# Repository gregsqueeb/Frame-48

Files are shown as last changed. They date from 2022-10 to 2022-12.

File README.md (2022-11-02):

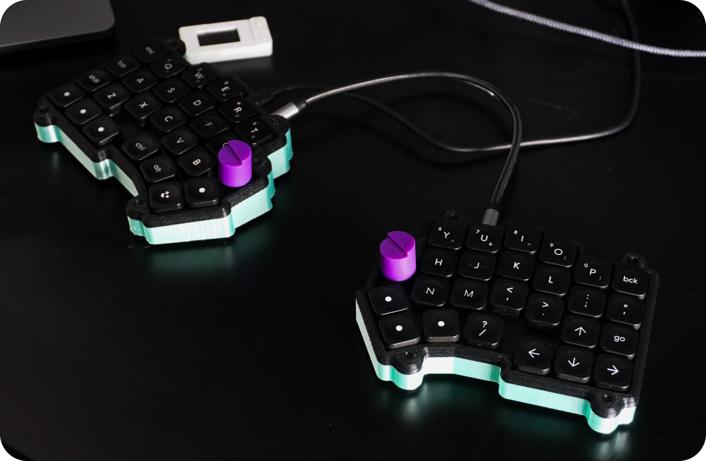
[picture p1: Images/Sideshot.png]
Side Shot

# Frame 48
 A handwired keyboard build created to use the [WorkLouder](https://worklouder.cc/) keycaps and inspired by the Void Ergo S! Runs QMK firmware and fully customizable with VIA configurator.

The Frame 48 is a 3d printed, handwired, split keyboard that was inspired by the [VOID ergo S](https://github.com/victorlucachi/void_ergo), running QMK Firmware on [Adafruit KB2040](https://www.adafruit.com/product/5302) controllers. Connection between the two halves of the keyboard is made with an aux cable via serial.

I suggest printing the case using a 0.4 mm nozzle, supports are not needed.

The brass inserts can be fixed in the bottom case by heating them and applying pressure with a soldering iron set to about 200-220C.

I created this iteration of the VOID Ergo S because I wanted my keyboard to have arrow keys as I use them a lot in my work as a product designer. I also wanted to build a keyboard that utilized [WorkLouder](https://worklouder.cc/) keycaps because I am a huge fan of their design and product. To be able to use their keycaps I needed to use choc style low profile switches which I couldn't get to work with the original Void Ergo S.

[Build Guide](/STL%20Files/Readme.md)

# Bill of Materials

* 52 diodes (tme.eu [link](https://www.tme.eu/ro/en/details/1n4148-dio/tht-universal-diodes/diotec-semiconductor/1n4148/)/aliexpress [link](https://www.aliexpress.com/item/32729204179.html))
* [Work Louder Keycaps](https://worklouder.cc/shop/wrk-legend/). This build was designed with these keycaps in mind.
* 52/54 choc switches [link](https://mechanicalkeyboards.com/shop/index.php?l=product_detail&p=6337)
* 24 AWG (0.2 mm2) wire
* 2 × [Adafruit KB2040](https://www.adafruit.com/product/5302)
* 1 × [Copper Wire](https://www.amazon.com/dp/B00XHD03EA) for switch connections
* 2 × EC11 Rotary Encoder (optional/aliexpress [link](https://www.aliexpress.com/item/32872039030.html) mounted to the plate using [this adapter](https://www.thingiverse.com/thing:3770166))
* 10 × M2×12 allen head screws (aliexpress [link](https://www.aliexpress.com/item/32966941844.html), 14mm overall length, 4mm diameter head)
* 10 × M2 brass inserts (aliexpress [link](https://www.aliexpress.com/item/4000585933306.html), 3.5mm outer diameter)
* 2 × PJ320A 3.5mm female audio connectors (aliexpress [link](https://www.aliexpress.com/item/32368285821.html))
* hot glue for securing the KB2040 to the bottom case (optional, but recommended), the audio connectors, and the switches.

# Pin assignment

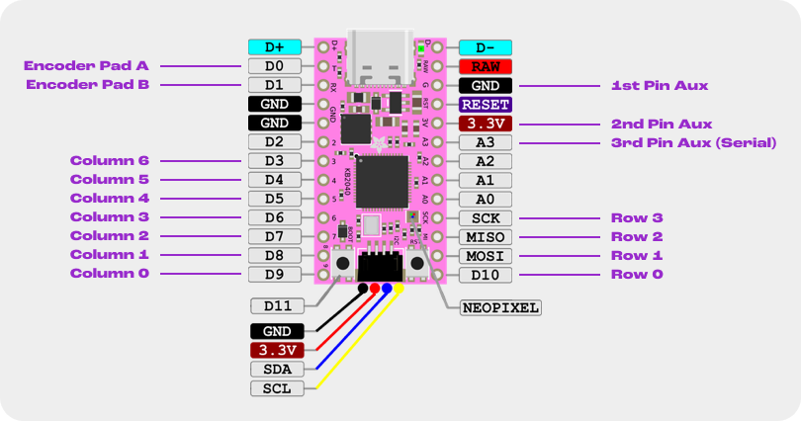
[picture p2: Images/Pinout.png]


    ROW0    ROW1    ROW2    ROW3
    D10     MOSI    MISO    SCK

    COL0    COL1    COL2    COL3    COL4    COL5    COL6
    D9      D8      D7      D6      D5      D4      D3

    Encoder Pad A           Encoder Pad B
    DO                      D1

    Serial Pin
    A3

*Matrix layout*
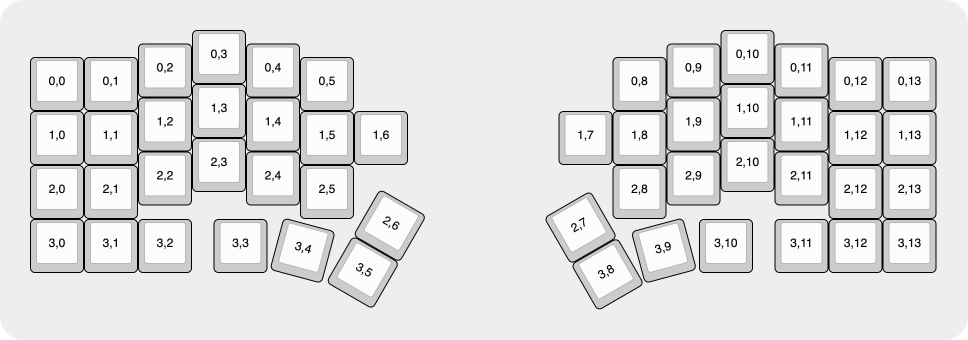
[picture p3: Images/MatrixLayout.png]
Matrix Layout

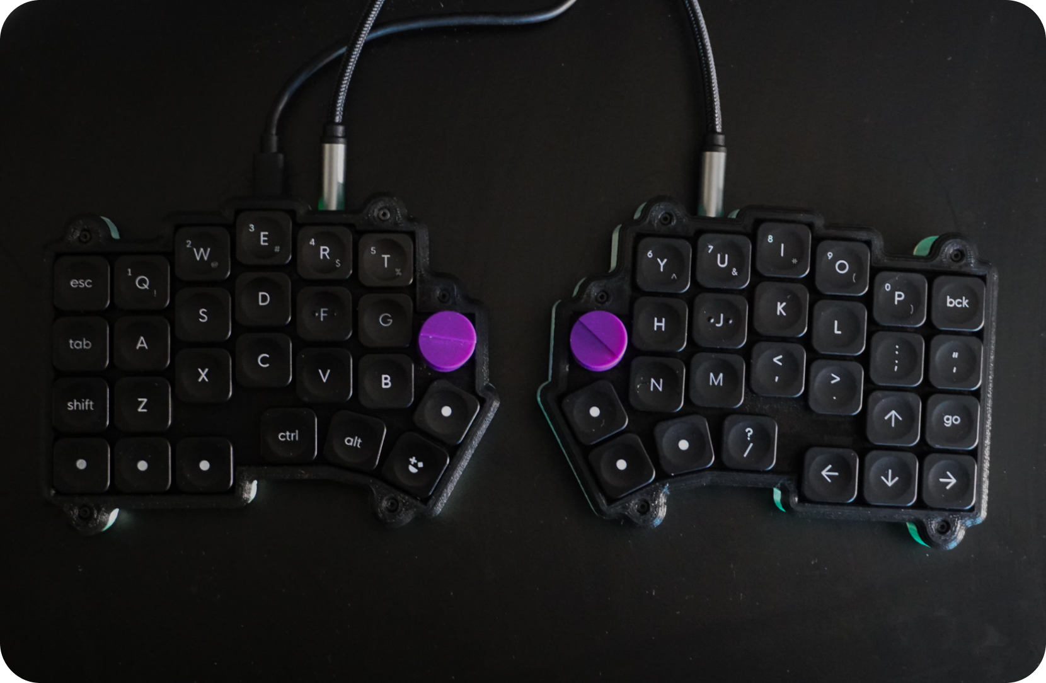
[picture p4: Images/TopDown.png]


# QMK Files
I have included the raw [QMK files](</QMK Files>) to compile the firmware in addition to the [copiled firmware](</Compiled Firmware>) for the keyboard to make it easier for people who don't want to compile their own firmware.

# [VIA Configurator Layout](https://usevia.app/)
I have created a VIA Configurator design for the board as well so it is easier to see what you are editing. You can upload the JSON file in [this folder](</VIA Files>) to the [Design tab](https://usevia.app/#/design) of VIA Configurator

# 💖 Inspiration and Thanks 💖
Huge shout out to [Victor Luchachi](https://victorlucachi.ro/) who makes absolutely beautiful products and renders. The design language of this build is based off of his Void Ergo S keyboard and his VOID 16 build was my very first keyboard build.

Thank you so much to [Joe Scotto](https://www.youtube.com/joescotto) for his awesome videos on handwiring keyboards. His pictures on reddit inspired me to use copper wiring on my build which ended up making the wiring process much easier and looks much much cleaner.

A massive fanboy shoutout to [WorkLouder](https://worklouder.cc/) for creating an absolutely beautiful and high quality product. The design of your keyboards and keycaps are amazing!

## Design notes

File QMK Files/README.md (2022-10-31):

1. Drag frame_48 in the qmk_firmware/keyboards/handwired/ folder

2. From the qmk_firmware folder run `make handwired/frame_48:via`

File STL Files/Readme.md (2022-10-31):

# Build Guide

1. Print all files :) 
    For the keyplates print them face down. You won't have to use supports for any of the prints.

2. Pop those switches in the key plate from the top.
switches

3. Bend all the diodes. I twist a little loop on the side that doesn't have a black line, and then perpendicular to the loop I bend the other half up.
diodes

4. Put the loop on the switch and solder them to the key
diode on key

5. Bend your wire for the rows, then bend the half of the diode that is facing straight up around the wire and solder it to the wire.
row soldered

6. Solder the columns all together. Use heat shrink tubing where the columns go over the rows.
row soldered

7. You will wire in the rotary encoder to the matrix. On the side with just two pins coming off the encoder, put a diode on one side and connect it to the rows, on the other pin connect that to the column. This will make the "push" work as a key. To wire the twist you will wire up the side with 3 pins. The outside pins connect to the microcontroller and the inside pin connects to ground on the microcontroller.

8. Wire columns and rows to the micro-controler. Use the pin diagram to make sure you are wiring the correct row/column to the correct pin.
Pinout

9. Solder wires to the TRRS port and wire that up to the micro controller. Make sure you are consistent with the wiring on both halfs.

10. Put everything in the case, use hot glue to secure the microcontroller and the TRRS connector.

11. Use your soldering iron ar ~200-220c and melt the M2 brass inserts into the bottom case.

12. Screw everything together!
Final

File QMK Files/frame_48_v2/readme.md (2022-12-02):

# Frame 48

frame

*A handwired keyboard build created to use the [WorkLouder](https://worklouder.cc/) keycaps and inspired by the Void Ergo S! Runs QMK firmware and fully customizable with VIA configurator.*

*The Frame 48 is a 3d printed, handwired, split keyboard that was inspired by the [VOID ergo S](https://github.com/victorlucachi/void_ergo), running QMK Firmware on [Adafruit KB2040](https://www.adafruit.com/product/5302) controllers. Connection between the two halves of the keyboard is made with an aux cable via serial.*

* Keyboard Maintainer: [Greg Mathews](https://github.com/gregsqueeb)
* Hardware Supported: Adafruit KB2040
* Hardware Availability:
  * 56 diodes (tme.eu [link](https://www.tme.eu/ro/en/details/1n4148-dio/tht-universal-diodes/diotec-semiconductor/1n4148/)/aliexpress [link](https://www.aliexpress.com/item/32729204179.html))
  * [Work Louder Keycaps](https://worklouder.cc/shop/wrk-legend/). This build was designed with these keycaps in mind.
  * 54/56 choc switches [link](https://mechanicalkeyboards.com/shop/index.php?l=product_detail&p=6337)
  * 24 AWG (0.2 mm2) wire
  * 2 × [Adafruit KB2040](https://www.adafruit.com/product/5302)
  * 1 × [Copper Wire](https://www.amazon.com/dp/B00XHD03EA) for switch connections
  * 2 × EC11 Rotary Encoder (optional/aliexpress [link](https://www.aliexpress.com/item/32872039030.html) mounted to the plate using [this adapter](https://www.thingiverse.com/thing:3770166))
  * 10 × M2×12 allen head screws (aliexpress [link](https://www.aliexpress.com/item/32966941844.html), 14mm overall length, 4mm diameter head)
  * 10 × M2 brass inserts (aliexpress [link](https://www.aliexpress.com/item/4000585933306.html), 3.5mm outer diameter)
  * 2 × PJ320A 3.5mm female audio connectors (aliexpress [link](https://www.aliexpress.com/item/32368285821.html))
  * hot glue for securing the KB2040 to the bottom case (optional, but recommended), the audio connectors, and the switches.

Make example for this keyboard (after setting up your build environment):

    make handwired/frame_48:default

Flashing example for this keyboard:

    make handwired/frame_48:default:flash

## Bootloader

Enter the bootloader:
    Press and hold the BOOT button down.
    Press and release the Reset button.
    Continue holding the BOOT button until you see the RPI-RP2 drive appear.
    You can now release but BOOT button.

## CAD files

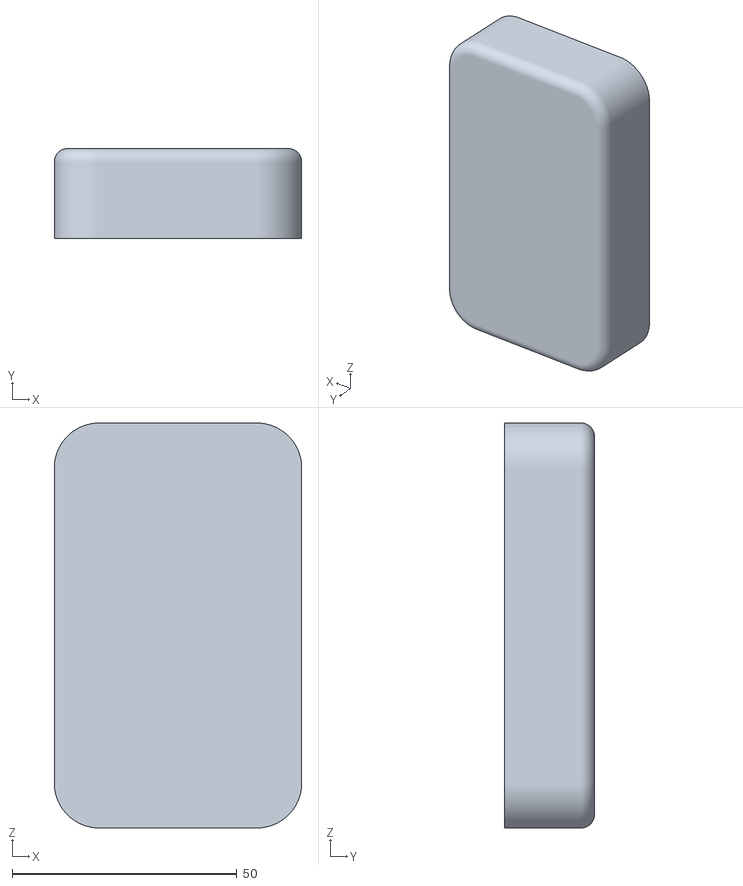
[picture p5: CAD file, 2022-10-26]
STL Files/Wrist Pad.stl
55.0 x 20.0 x 90.0

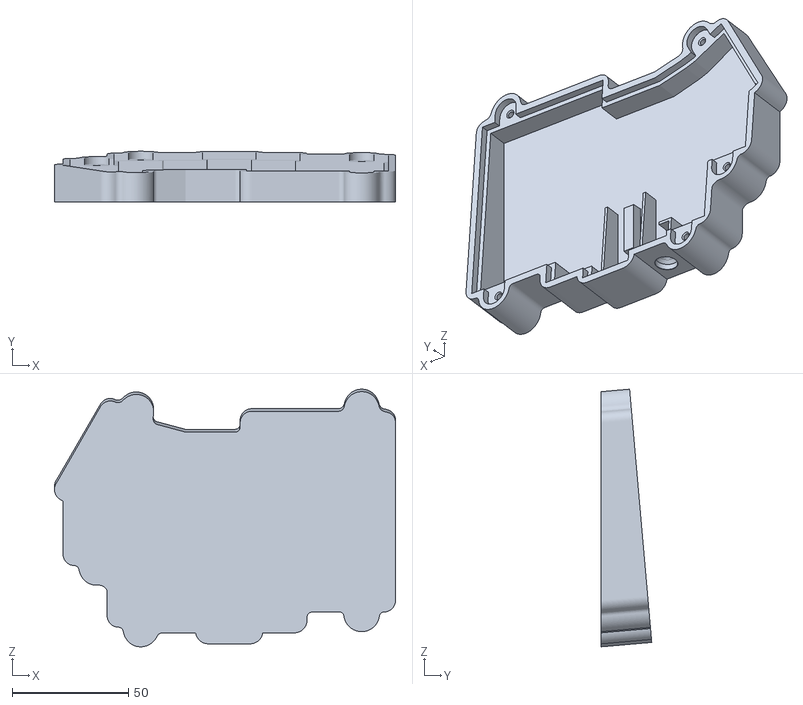
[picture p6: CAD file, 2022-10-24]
STL Files/Base-Right.stl
146.6 x 21.7 x 110.8

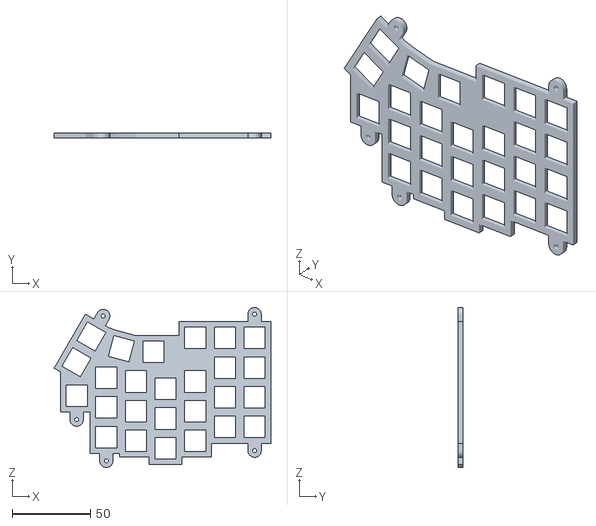
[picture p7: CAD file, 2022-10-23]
STL Files/KeyPlate-Left.stl
139.0 x 3.00 x 102.5

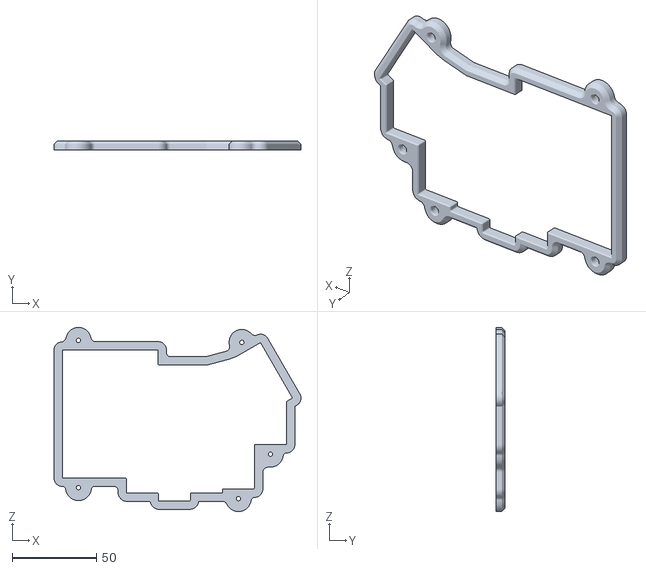
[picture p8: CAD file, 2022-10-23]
STL Files/TopPlate-Left.stl
146.6 x 5.50 x 109.3

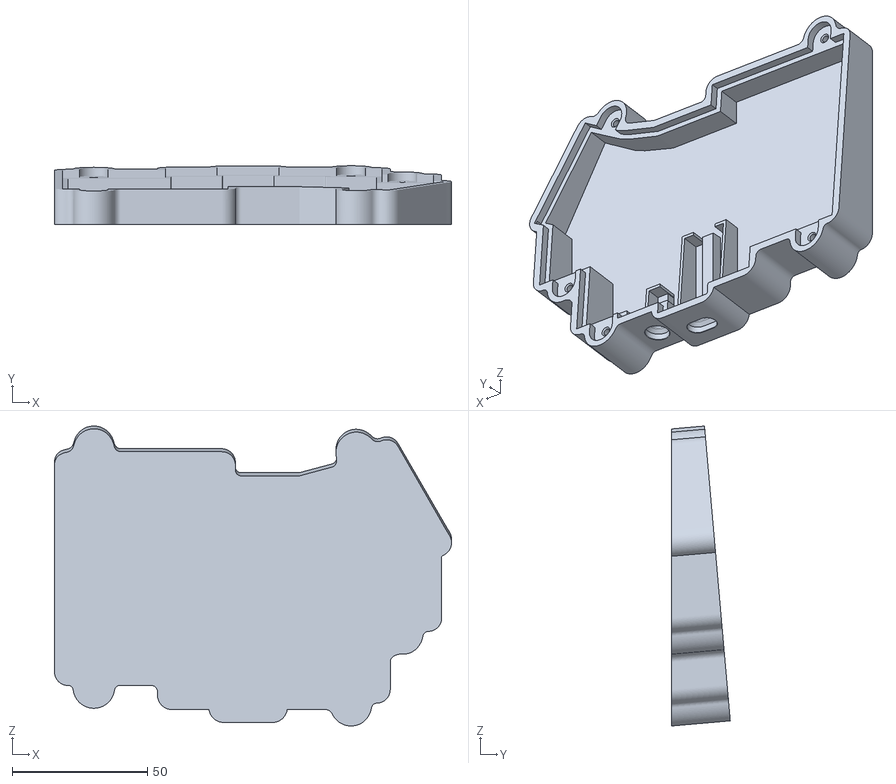
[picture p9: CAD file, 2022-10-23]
STL Files/Base-Left.stl
146.6 x 21.6 x 110.8

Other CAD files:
STL Files/TopPlate-Right.stl

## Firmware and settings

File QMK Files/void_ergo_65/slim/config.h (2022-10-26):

/*
Copyright 2022 Greg Mathews

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
You should have received a copy of the GNU General Public License
along with this program.  If not, see <http://www.gnu.org/licenses/>.
*/

#pragma once

#include "config_common.h"

#define PRODUCT VOID ERGO 65

/*
 * Keyboard Matrix Assignments
 *
 * Change this to how you wired your keyboard
 * COLS: AVR pins used for columns, left to right
 * ROWS: AVR pins used for rows, top to bottom
 * DIODE_DIRECTION: COL2ROW = COL = Anode (+), ROW = Cathode (-, marked on diode)
 *                  ROW2COL = ROW = Anode (+), COL = Cathode (-, marked on diode)
 *
 */
#define MATRIX_ROW_PINS \
    { B6, B2, B3, B1 }
#define MATRIX_COL_PINS \
    { B5, B4, E6, D7, C6, D4, D0 }

/* Encoder pins */
#define ENCODERS_PAD_A \
    { D3 }
#define ENCODERS_PAD_B \
    { D2 }

#define ENCODERS_PAD_A_RIGHT \
    { D3 }
#define ENCODERS_PAD_B_RIGHT \
    { D2 }

#define ENCODER_DIRECTION_FLIP

/* Split Keyboard specific options, make sure you have 'SPLIT_KEYBOARD = yes' in your rules.mk, and define SOFT_SERIAL_PIN. */
#define USE_SERIAL
#define SOFT_SERIAL_PIN F4 // or D1, D2, D3, E6
#define SELECT_SOFT_SERIAL_SPEED 0
#define MASTER_LEFT

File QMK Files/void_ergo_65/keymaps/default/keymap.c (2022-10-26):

/* Copyright 2022 Greg Mathews
 *
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
 * You should have received a copy of the GNU General Public License
 * along with this program.  If not, see <http://www.gnu.org/licenses/>.
 */
#include QMK_KEYBOARD_H

// Defines names for use in layer keycodes and the keymap
enum layer_names {
  _QWERTY,
  _RAISE,
  _LOWER,
  _ADJUST
};

const uint16_t PROGMEM keymaps[][MATRIX_ROWS][MATRIX_COLS] = {

/* OWERTY
 * |---------------------------------------------------------------------.             .--------------------------------------------------------------|
 * |KC_ESC,    KC_Q,    KC_W,    KC_E,    KC_R,    KC_T,  KC_KB_VOLUME_UP,               KC_NO,   KC_Y,     KC_U,    KC_I,    KC_O,   KC_P,   KC_BSPC |
 * |--------+--------+--------+--------+--------+--------+----------------|            |--------+--------+--------+--------+--------+--------+--------|
 * |KC_TAB,    KC_A,    KC_S,    KC_D,    KC_F,    KC_G,  KC_MPLY,                       KC_NO,  KC_H,    KC_J,    KC_K,    KC_L,    KC_SCLN, KC_QUOT |
 * |--------+--------+--------+--------+--------+--------+----------------|            |--------+--------+--------+--------+--------+--------+--------|
 * |KC_LSFT,    KC_Z,    KC_X,    KC_C,    KC_V,    KC_B,  KC_SPC,                       KC_SPC,   KC_N,    KC_M, KC_COMM,  KC_DOT,  KC_UP,   KC_ENTER|
 * |--------+--------+--------+--------+--------+--------+--------------------|        |--------+--------+--------+--------+--------+--------+--------|
 *  KC_NO,    KC_EQUAL,   LOWER,  KC_LCTL, KC_RALT,   KC_LCMD,  KC_KB_VOLUME_DOWN|     | KC_NO,   KC_RCMD,  RAISE,  KC_SLASH, KC_LEFT, KC_DOWN, KC_RIGHT
 *                                       |------------------------------------|        |--------------------------|
 */
[_QWERTY] = LAYOUT_void_ergo_65(
    KC_ESC,     KC_Q,     KC_W,       KC_E,       KC_R,     KC_T,     KC_KB_VOLUME_UP,            KC_NO,      KC_Y,       KC_U,         KC_I,       KC_O,     KC_P,     KC_BSPC,
    KC_TAB,     KC_A,     KC_S,       KC_D,       KC_F,     KC_G,     KC_MPLY,                    KC_NO,      KC_H,       KC_J,         KC_K,       KC_L,     KC_SCLN,  KC_QUOT,
    KC_LSFT,    KC_Z,     KC_X,       KC_C,       KC_V,     KC_B,     KC_SPC,                     KC_SPC,     KC_N,       KC_M,         KC_COMM,    KC_DOT,   KC_UP,    KC_ENTER,
    KC_MINUS,   KC_EQUAL, MO(_LOWER), KC_LCTL,    KC_RALT,  KC_LCMD,  KC_KB_VOLUME_DOWN,          KC_NO,      KC_RCMD,    MO(_RAISE),   KC_SLASH,      KC_LEFT,  KC_DOWN,  KC_RIGHT
),

[_LOWER] = LAYOUT_void_ergo_65(
    KC_ESC,     KC_EXLM,  KC_AT,       KC_HASH,    KC_DLR,   KC_PERC,  KC_TRNS,                   KC_TRNS,    KC_CIRC,    KC_AMPR,     KC_ASTR,    KC_LPRN,  KC_RPRN,  KC_BSPC,
    KC_TRNS,    KC_LEFT,  KC_DOWN,     KC_UP,      KC_RIGHT, KC_TRNS,  KC_TRNS,                   KC_TRNS,    KC_LEFT,    KC_DOWN,     KC_UP,      KC_RIGHT, KC_TRNS,  KC_TRNS,
    KC_TRNS,    KC_TRNS,  KC_TRNS,     KC_TRNS,    KC_TRNS,  KC_TRNS,  KC_TRNS,                   KC_TRNS,    KC_TRNS,    KC_TRNS,     KC_TRNS,    KC_TRNS,  KC_TRNS,  KC_TRNS,
    KC_TRNS,    KC_TRNS,  MO(_LOWER),  KC_TRNS,    KC_TRNS,  KC_TRNS,  KC_TRNS,                   KC_TRNS,    KC_TRNS,    MO(_RAISE),  KC_ENT,       KC_RALT,  KC_TRNS,  KC_TRNS
),

[_RAISE] = LAYOUT_void_ergo_65(
    KC_ESC,     KC_1,     KC_2,     KC_3,       KC_4,     KC_5,     KC_TRNS,                      KC_TRNS,  KC_6,       KC_7,       KC_8,       KC_9,     KC_0,     KC_BSPC,
    KC_TRNS,    KC_TRNS,  KC_TRNS,  KC_TRNS,    KC_TRNS,  KC_TRNS,  KC_TRNS,                      KC_TRNS,  KC_MINS,    KC_EQL,     KC_LCBR,    KC_RCBR,  KC_PIPE,  KC_GRV,
    KC_TRNS,    KC_TRNS,  KC_TRNS,  KC_TRNS,    KC_TRNS,  KC_TRNS,  KC_TRNS,                      KC_TRNS,  KC_UNDS,    KC_PLUS,    KC_LBRC,    KC_RBRC,  KC_BSLS,  KC_TILD,
    KC_TRNS,    KC_TRNS,  MO(_LOWER),  KC_TRNS,  KC_SPC,   KC_TRNS,  KC_TRNS,                     KC_TRNS,  KC_TRNS,    MO(_RAISE), KC_ENT,     KC_RALT,  KC_TRNS,  KC_TRNS
),
[_ADJUST] = LAYOUT_void_ergo_65(
    KC_TRNS,     KC_TRNS,  KC_TRNS,       KC_TRNS,    KC_TRNS,   KC_TRNS,  KC_TRNS,                   KC_TRNS,    KC_TRNS,    KC_TRNS,     KC_TRNS,    KC_TRNS,  KC_TRNS,  KC_TRNS,
    KC_TRNS,    KC_TRNS,  KC_TRNS,     KC_TRNS,      KC_TRNS, KC_TRNS,  KC_TRNS,                   KC_TRNS,    KC_TRNS,    KC_TRNS,     KC_TRNS,      KC_TRNS, KC_TRNS,  KC_TRNS,
    KC_TRNS,    KC_TRNS,  KC_TRNS,     KC_TRNS,    KC_TRNS,  KC_TRNS,  KC_TRNS,                   KC_TRNS,    KC_TRNS,    KC_TRNS,     KC_TRNS,    KC_TRNS,  KC_TRNS,  KC_TRNS,
    KC_TRNS,    KC_TRNS,  MO(_LOWER),  KC_TRNS,    KC_TRNS,  KC_TRNS,  KC_TRNS,                   KC_TRNS,    KC_TRNS,    MO(_RAISE),  KC_TRNS,       KC_TRNS,  KC_TRNS,  KC_TRNS
),
};

layer_state_t layer_state_set_user(layer_state_t state) {
    return update_tri_layer_state(state, _LOWER, _RAISE, _ADJUST);
}

/*
 * ROTARY ENCODER
 */



#if defined(ENCODER_MAP_ENABLE)
const uint16_t PROGMEM encoder_map[][NUM_ENCODERS][2] = {
    [_QWERTY] =   { ENCODER_CCW_CW(KC_MINUS, KC_EQUAL), ENCODER_CCW_CW(KC_MINUS, KC_EQUAL)  },
    [_LOWER] =  { ENCODER_CCW_CW(KC_MINUS, KC_EQUAL), ENCODER_CCW_CW(KC_MINUS, KC_EQUAL)  },
    [_RAISE] =  { ENCODER_CCW_CW(KC_MINUS, KC_EQUAL), ENCODER_CCW_CW(KC_MINUS, KC_EQUAL)  },
    [_ADJUST] = { ENCODER_CCW_CW(KC_MINUS, KC_EQUAL), ENCODER_CCW_CW(KC_MINUS, KC_EQUAL)  },
};
#endif



// bool encoder_update_kb(uint8_t index, bool clockwise) {
//     return encoder_update_user(index, clockwise);
// }

// bool encoder_update_user(uint8_t index, bool clockwise) {
//     if (index == 0) { /* First encoder */
//         if (clockwise) {
//             tap_code(dynamic_keymap_get_keycode(biton32(layer_state), 0, 6));
//         } else {
//             tap_code(dynamic_keymap_get_keycode(biton32(layer_state), 3, 6));
//         }
//     } else if (index == 1) { /* Second encoder */
//         if (clockwise) {
//             // tap_code(dynamic_keymap_get_keycode(biton32(layer_state), 4, 0));
//             tap_code(KC_VOLU);
//         } else {
//             // tap_code(dynamic_keymap_get_keycode(biton32(layer_state), 7, 0));
//             tap_code(KC_VOLU);
//         }
//     }
//     return true;
// }

void matrix_init_user(void) {

}

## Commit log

2022-10-23 Initial Creation
    [Base-Left.stl, Base-Right.stl, KeyPlate-Left.stl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]
2022-10-24 Updating the base file to remove the USB port completely and adding a readme for the QMK files
    [Base-Right.stl]
2022-10-24 Updating the number of required switches and diodes
2022-10-24 Updating the number of Diodes needed
2022-10-24 UPdated Pin Image to fix typo
2022-10-26 Refactored to use the encoder matrix. Also added wrist rests.
    Using the encoder matrix allowed both encoders to work!
    [Wrist Pad.stl]
2022-10-26 Updating the via layout to support encoders
2022-10-31 Updating the keymaps to avoid shifting the right keys
    [keymap.c]
2022-11-02 Updating the number of keys/diodes you need.
2022-12-02 Adding the V2 of the board

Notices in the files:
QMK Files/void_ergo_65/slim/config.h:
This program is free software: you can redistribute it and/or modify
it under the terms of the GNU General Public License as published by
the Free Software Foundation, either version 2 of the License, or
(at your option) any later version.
